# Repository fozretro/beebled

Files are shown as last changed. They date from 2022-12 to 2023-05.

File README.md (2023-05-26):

BeebLED
=======

So after nearly a year at this point (24th Nov 2022) of learning electronics, "re"collecting various retro computers, modifying and fixing them. I figured I would revist a childhood dream to have my own scrolling message board! Just like the ones down my local kebab shop! So lets build an LED matrix scroller for the Beeb! The proof of concept can be found [here](https://www.reddit.com/r/beneater/comments/xq2d4h/completed_6502_project_with_led_scroller/).

You can also see a demo video [here](https://drive.google.com/file/d/1L_YhwlXpUD0SaMJsGKrx3CFpbm8zI_nu/view).


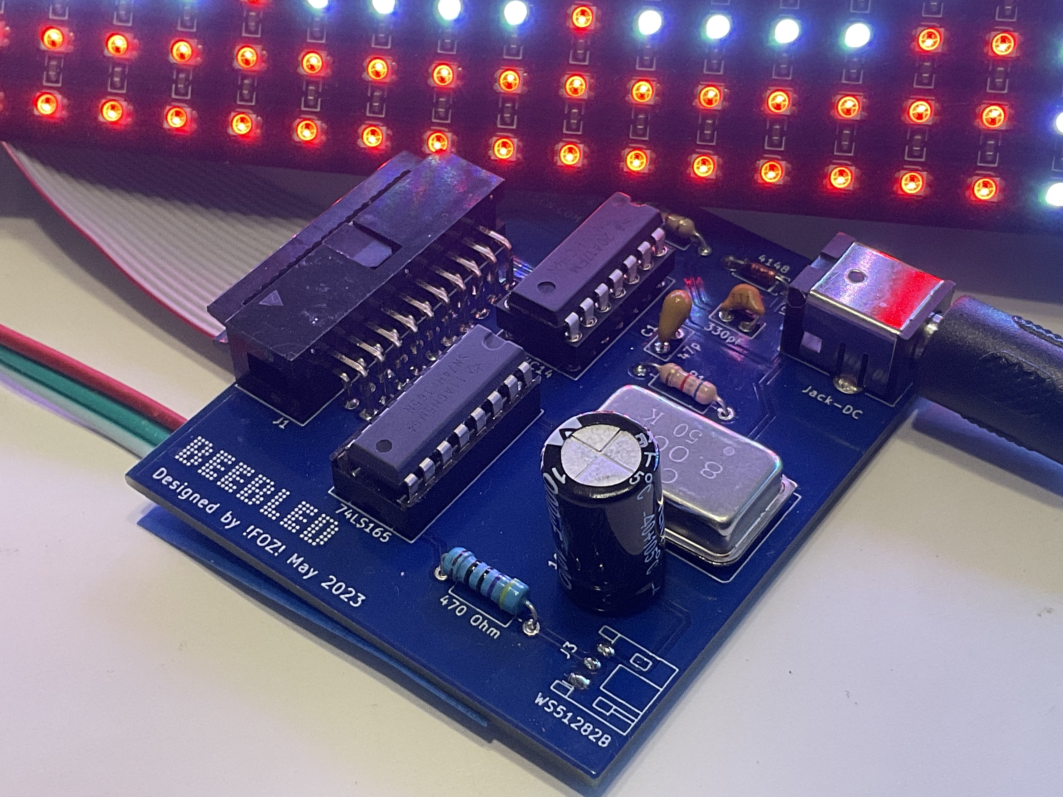
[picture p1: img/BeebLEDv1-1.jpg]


Credits
=======
- [Ben Eater](https://eater.net/6502), for opening my eyes to the joy of hardware and software building together!
- [Anders Brauner Nielsen](https://abnielsen.com), his well timed [blog](https://abnielsen.com/2021/12/23/ws2812b-rgb-lights-on-a-6502/) turned up (to my suprise) in my web searches for 6502 and LEDs! His ingenious circuit, with some additional components and modificaitons is at the core of this solution! Thank you Anders!
- [StarDot Forums](https://stardot.org.uk/forums/), the place for advice and encourgement for all your Acorn projects! This project uses [BeebASM](https://github.com/stardot/beebasm), [UPURSFS](https://www.retro-kit.co.uk/UPURS/) and [Visual Studio Code Extension for BeebASM](https://marketplace.visualstudio.com/items?itemName=simondotm.beeb-vsc). The authors of these amazing tools also hangout on stardot!

Usage
=====

It is a little early in development to complete this section, though my eventual goal is some kind of ROM, possibly using sideways RAM to avoid using the main RAM. Maybe even a VDU driver to plot stuff on the LED display? For now please see [this StarDot Forum thread](https://stardot.org.uk/forums/viewtopic.php?f=3&t=26047).

Developmet Tools
================

The ```/dist``` always contains the latest .ssd, but if you want to try to build it locally this section contains my notes on how I set things up with UPURSFS.

- Shift+Command+B bulds stuff and copies over to ```/dev/beebled``` and ```/dist```
- Shift+Ctrl+T launches the emulator (hard coded to where I have it)
- See below for connecting Beeb to the ```/dev/beebled``` folder to test hardware

Running UPURSFS and TubeHost
----------------------------

This enables the fastest possible inner loop for development, build on the Mac and instantly the compiled output is visble to the connected Beeb! This is especially useful since the only way (currently without mocking) is to see results is on real hardware.

**On the Beeb**, have UPURSFS ROM installed and pressing U+Break, U+Crl+Break or U+Shift+Break. If it says (No RTS) things are not connected - check the cable. See general instructions in the ```/bin/UPURSFS/Tubehost/README.txt```. ```*HSTATUS``` is a good test command. Press Ctrl+U+Break to boot the ```/dev/beebled``` disc on the Beeb. Note if you have ```Configure BOOT``` setup you have to use Ctrl+U+Break, if this gets frustrating just switch auto boot off.

**On the Mac**, you need to run ```/bin/UPURSFS/TubeHost/TubeHost.perl```. I had some issues running it and posted on StarDot forums what I found and my fix, see [here](https://stardot.org.uk/forums/viewtopic.php?f=3&t=24976) and also other tips.

```perl ./bin/UPURSFS/TubeHost/TubeHost.perl -U /dev/cu.usbserial-FTCL544Z```

By default the files it serves up to the BBC are in ```$HOME/Beeb_Disks```, however the above script has been modified to serve from ```/dev```. Note that when working on the files on the Beeb changes are also instantly reflected as well. For example when editing the sprites using the native Acorn GFX sprite editor and commands as described below.

Updating Sprites
----------------

Sprites can be used in the scroller and use the Acorn GFX sprite file format. You must then use the Acorn GFX Sprites ROM if on Master (as shown below), or one of the others if on other systems to edit. Note if you use a Master to edit the sprites and use the ROM in Sideways RAM the reminder of the ram bank is used for your sprites storage nice! Bellow is using indirect way of loading via memory as on UPURS ```SRLOAD``` command hangs.

```*LOAD R.SPRITES 3000```

```*SRWRITE 3000 6000 8000 4```

```*SLOAD Sprites```

Use commands like ...

```*SEDIT 1```

```*SDELETE 1```

```*SRENUMBER 4 1```

Then use to save ... (last two commands if on UPURS only)

```*SSAVE Sprites```

```*HTSTATUS```

```*CLOSE```

TODO's
======

Software
--------
- Add support #s command to support sprites of different heights (hard coded to 8)
- Build config. for the MODE2 emulation of LED output (consider using MODE 8)
- Remove hard coded mode2 calculated rows table and replace with asm macro script?
- Add config to support different size led panels, constants and logic behavior hard codedto 11x44
- It is not optimized other than having a secondary display buffer to ensure consistent timing output to the LED. Likely when I share this further, it can be optimized even further with feedback. 
- Implement 1 pixel scroll (currently 2 pixel)
- Eventually I would like to have the code in a ROM, e.g. *BEEBLED Hello World, or *BEEBLED #m3000 (displays whats on screen), and/or maybe a VDU driver? Not sure what to do about storage, use sideways ram if ROM loaded into sideways ram bank? Otherwise take PAGE?

Hardware
---------
- Experiment with adding additional 11x44 pixel matrix for longer and/or wider displays

Development Diary
=================

26th May 2023
-------------
- Made some fixes to the schematic and PCB design
- 1/ flipped diode around
- 2/ removed pcb JST connector (could not find one for JST SM based connectors) and replaced with pin headers and annotated 
- 3/ increased footprint size of 1000uF capacitor 
- 4/ added a little more labelling on the pcb
- 5/ updated to v1.2
- I kinda like it without a case and don't have the skills or hardware to design one (nor time, space, $ to invest at this point in that hobby)
- So I am thinking once the hardware design is stable I will turn full attention to the software TODO's above
- Next step is to double check above changes and send off for a new PCB, build it and test it

20th May 2023
-------------
- Week prior to today, the PCB arrived from PCBWay, along with various components
- Assemebling on and off during weekday evenings
- First test failed!
- Made a quick hack to the code to simply flip 1 LED off and on with a keypress, should add this in the future as a flag
- After compariing with the prototype and studying the PCB layout, realized i flipped the diode footprint on the PCB layout!
- Also found that the matrix JST connector I used is to small
- Have the breadboard prototype to compare signals really helped!
- After a soldering the matrix fly lead diretly to the PCB for now, and flipping the diode, success!
- Next job fix the PCB design, and source larger JST connector, also publish a BOM
- Then build the next version!

5th May 2023
------------
- Reproduce the circuit in Kicad
- Design the PCB in Kicad
- Build PCB via PCBWay
- Share the designs

Dec 25th
--------
- Removed hard coded font and used OS API to get character definitions

Dec 24th
--------
- Updated flash screen with new BeebLED logo
- Shorter default message with new holiday themed sprite!
- Published repo on fozretro GitHub
- Made a video shared on StarDot

Dec 21-23rd
-----------
- Implemented expressing sprite, text color changes and pause in message string

```#cX - Text color where x is 0-7```

```#pX - Pause for 0-9 seconds```

```#sX - Scroll on sprite 0-9 for now assumed 8 pixels with, but can be variable width```

```#dX - Display sprite 0-9 then scroll```

- Acorn GFX sprites are stored in logical top-down order for rows but right-left order horizontally, would love to know why?!?! Optimization in the sprite plotting code?

Dec 20th
--------
- Fixed the colors on the LED since moving to how true Mode 2 pixels are encoded
- Its not the most performant code right now - more tables or something needed in the future
- Refactored a little into two other .asm files
- Added some commands as follows

```#cX - Text color where x is 0 to 7```

```#sp - Pause for 0 to 9 seconds```

```#d - Display sprite 0```

Dec 19th
--------
- Broke the pixel coloring being output to the LED, since using true Mode 2 pixel encoding
- Removed hard coded scrolling message and splash screen
- Now loads from Acorn GFX sprite file and text file respectively
- Very strange format for sprites not sure how performant it will be to scroll in sprites
- Oh and implemented a debug feature to write to mode 2 screen as well as the LED
- Made sure all files under ```/dev/beebled``` are also copied to ```.ssd```

Dec 18th
--------
- In understanding the Acorn GFX sprite editor I mostly spent a few hours realizing my encoding for MODE 2 I had in mind was wrong and does not match the Beebs after all!
- So I wanted some way to easily add graphics into the scroller and decided to investigate the Acorn GFX sprite editor and its file format ... (later read same on StarDot doh)
    - File length - 2 bytes (including these two bytes)
    - Number of spirtes in file (not zero based) - 1 byte
    - Sprite
        - width (in bytes - base zero) - 1 byte
        - height (in bytes - base zero) - 1 byte
        - size (in bytes) - 2 byte
        - mode - 1 byte
        - id - 1 byte
        - data - bytes
- Ideas for message text format and making BeebLED configurable!
    - Scroll on a sprite, sprites smaller than 11 pixels in height get a border
    - Option to just display it a sprite on a clear screen then scroll
    - Scroll text uses built in font (for now!)
    - Pause the scrolling for x seconds
    - Change scroll direction 
    - Syntax ideas... ```#S1 #P5 This is the rest of the message... I #S2 my Beeb!```
    - Have sprites dynamically loaded, if ```Sprites``` file exists
    - Have message dynanically loaded, if ```Message``` file exists
- Added GFX ROMS and setup dummy config files Sprites and Message
- Drew the very early prototype splash screen from Sarah and stores in ```Sprites```

Dec 16th
--------
- Added basic argument reading to pass in different messages (really just to play with it for now - want to make a set of ROM commands for this). Now supports ```*BEEBLED My Message!```
- Exit the app on key press back to command line

Dec 12th
--------
- Fixed most of the gitter I  was seeing by remove fly leds, attach end of cable direct to breadboard - it still occurs now and again - but not enough to stop me progressing with some more of the software side of things

Dec 11th
--------
- Ported over code from my Ben Eater project which used a different compiler and memory addreses.
- Success! We have LED scroller powered by a BBC Micro!
- Well with the some glitching, which I think is due to fly leads etc. So I think I will atttempt to direct connect the User Port cable end more directly to the board with some pins.
- This is quite a milestone, so once I can fix the glitching I'll do a share on stardot
- Next up make the software a bit more accessible, to pass a message in from the command line
- After that likely I can split my time between software and progressing a schematic and pcb

Dec 10th
---------
- After much reading and re-learning I probed each of the steps in converting the Beebs clock pulse into a pulse to latch the data into the serial output IC. I noticed the inversion happening and decided to use an additional input/output on the 74HC14, 6A and 6Y, to have pulse generated on the actual Beebs pulse, not the inversion of it.
- I also found that if I have the LEDs to bright, the signal I think suffers and LEDs remain on or don't show the correct color. I probably need some more smoothing capactitors in some place?!?! Anyway the software fix was to low the brightness and hey presto it all stablized! I fill the 11x44 matrix with pixels and toggled them on and off with success. 
- Next up more fun with software for a bit! Scrolling message here we come!

Dec 4th
-------
- WIP > Coping over some code from my very first prototype [here](https://www.reddit.com/r/beneater/comments/wd6irw/ben_eater_6502_computer_driving_ws2812b_rgb_leds/) - trigger based on keypress as no timer code setup yet
- Partial success I can toggle an LED and show a strip of them..... but the signals are out
- However on closer inspection the data signal to LED matrix is missing the first bit of each byte sent via CB2, it sends a 0 and then only the first 7 bits from CB2 are being sent. Looking at it through my scope I can see that the small pulse sent to the PL pin is being sent to soon before data on CB2 starts to be sent. Afterwards due to timing the second pulse picks up the tail end of the first bit of data from CB2, but by this time the circuit has of course sent 1 of 8 bits.
-When I look at the data sheet for mode 110 it does show this as well. The odd thing is on the Ben Eater system above it worked fine (I plan to do more compares at the weekend with my scope).

Dec 2nd, 3rd
--------
- Built a new breadboard of the circuit to send to LED matrix I used for my Ben Eater computer [here](https://www.reddit.com/r/beneater/comments/wd6irw/ben_eater_6502_computer_driving_ws2812b_rgb_leds/)
- Tested on the above and works fine - yay!
- Will it work on the Beeb though? Is the data line to long? Had sights of clitchs on the original breadboard when this was the case?

27th Nov
--------
- Labelled up some GND, CB1 and CB2 fly leads from the cable socket ready to plug into breadboard
- Write some basic code that sets up the VIA and send bytes (keyboard input)so I could monitor with my scope to check the basic serial output is working from beeb user port. Monitoring CB1 and CB2 shows signals as expected. Nice!
- Also fixed !BOOT

26th Nov
--------
- Udpated the README with some info on the dev tools and captured pinout for user port
- Some good notes [here](https://stardot.org.uk/forums/viewtopic.php?t=11671) on testing user port
- I tested my cable pins do have 5v on them yay!

24th Nov
--------
- Built a BBC user port cable and tested continuity it with my meter
- Setup this project with various VSCode tasks and levergaging the UPURSFS file system to make stuff available instantly on the connected Beeb for testing.

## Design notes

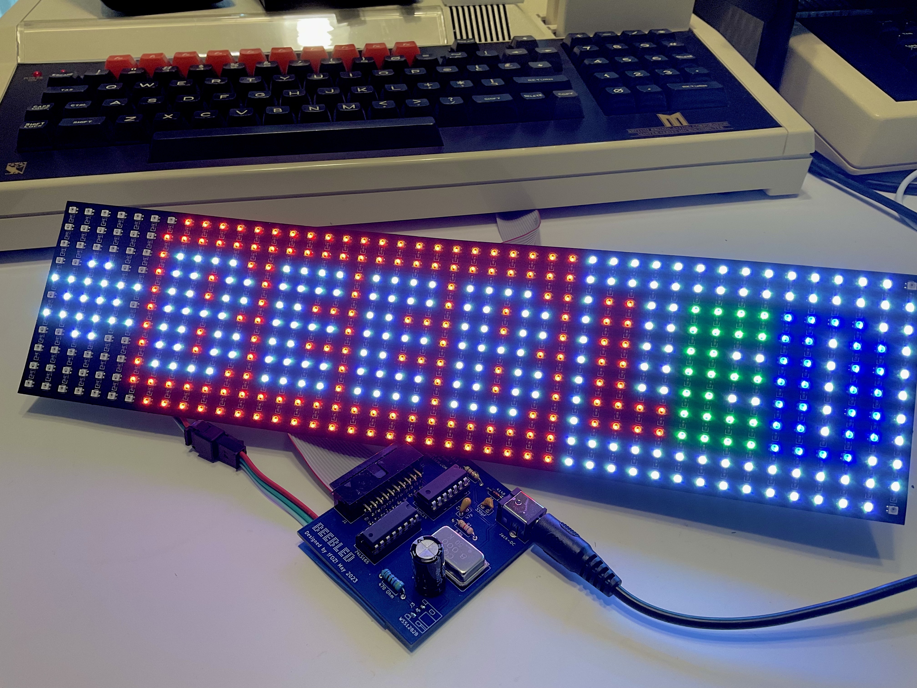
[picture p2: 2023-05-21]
img/BeebLEDv1-1Large.jpg

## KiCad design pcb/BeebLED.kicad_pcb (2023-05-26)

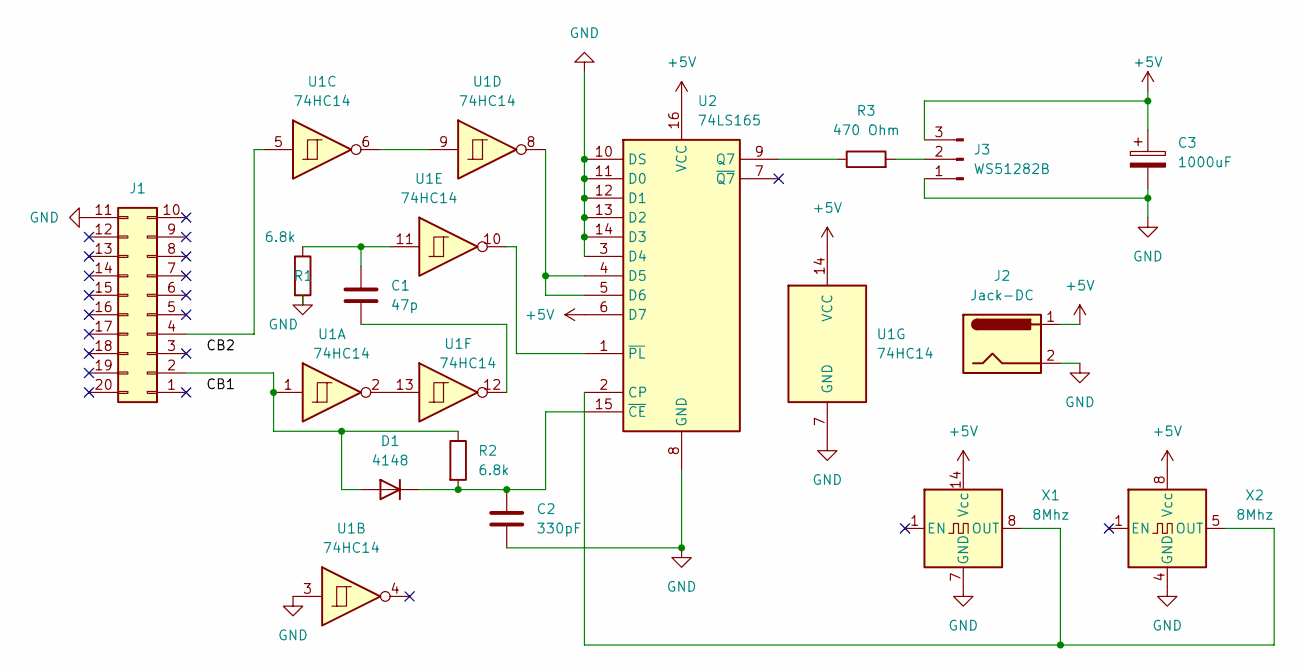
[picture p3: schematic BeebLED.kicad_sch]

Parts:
C1: 47p; C_Disc_D5.0mm_W2.5mm_P2.50mm
C2: 330pF; C_Disc_D5.0mm_W2.5mm_P2.50mm
C3: 1000uF; CP_Radial_D10.0mm_P5.00mm
D1: 4148; D_A-405_P7.62mm_Horizontal
J1: IDC-Header_2x10_P2.54mm_Horizontal
J2: Jack-DC; BarrelJack_CUI_PJ-063AH_Horizontal_CircularHoles
J3: WS51282B; PinHeader_1x03_P2.54mm_Vertical
R1, R2: 6.8k; R_Axial_DIN0207_L6.3mm_D2.5mm_P10.16mm_Horizontal
R3: 470 Ohm; R_Axial_DIN0207_L6.3mm_D2.5mm_P10.16mm_Horizontal
U1: 74HC14; DIP-14_W7.62mm_Socket
U2: 74LS165; DIP-16_W7.62mm_Socket
X1: 8Mhz; Oscillator_DIP-14
X2: 8Mhz; Oscillator_DIP-8

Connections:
+5V: C3.1, J2.1, J3.3, U1.14 (VCC), U2.6 (D7), U2.16 (VCC), X1.14 (Vcc), X2.8 (Vcc)
GND: C2.2, C3.2, J1.11, J2.2, J3.1, R1.2, U1.3, U1.7 (GND), U2.3 (D4), U2.8 (GND), U2.10 (DS), U2.11 (D0), U2.12 (D1), U2.13 (D2), U2.14 (D3), X1.7 (GND), X2.4 (GND)
unnamed: C1.1, R1.1, U1.11
unnamed: C1.2, U1.12
unnamed: C2.1, D1.2 (K), R2.2, U2.15 (~CE)
unnamed: D1.1 (A), J1.2, R2.1, U1.1
unnamed: J1.4, U1.5
unnamed: J3.2, R3.2
unnamed: R3.1, U2.9 (Q7)
unnamed: U1.6, U1.9
unnamed: U1.8, U2.4 (D5), U2.5 (D6)
unnamed: U1.10, U2.1 (~PL)
unnamed: U1.2, U1.13
unnamed: U2.2 (CP), X1.8 (OUT), X2.5 (OUT)

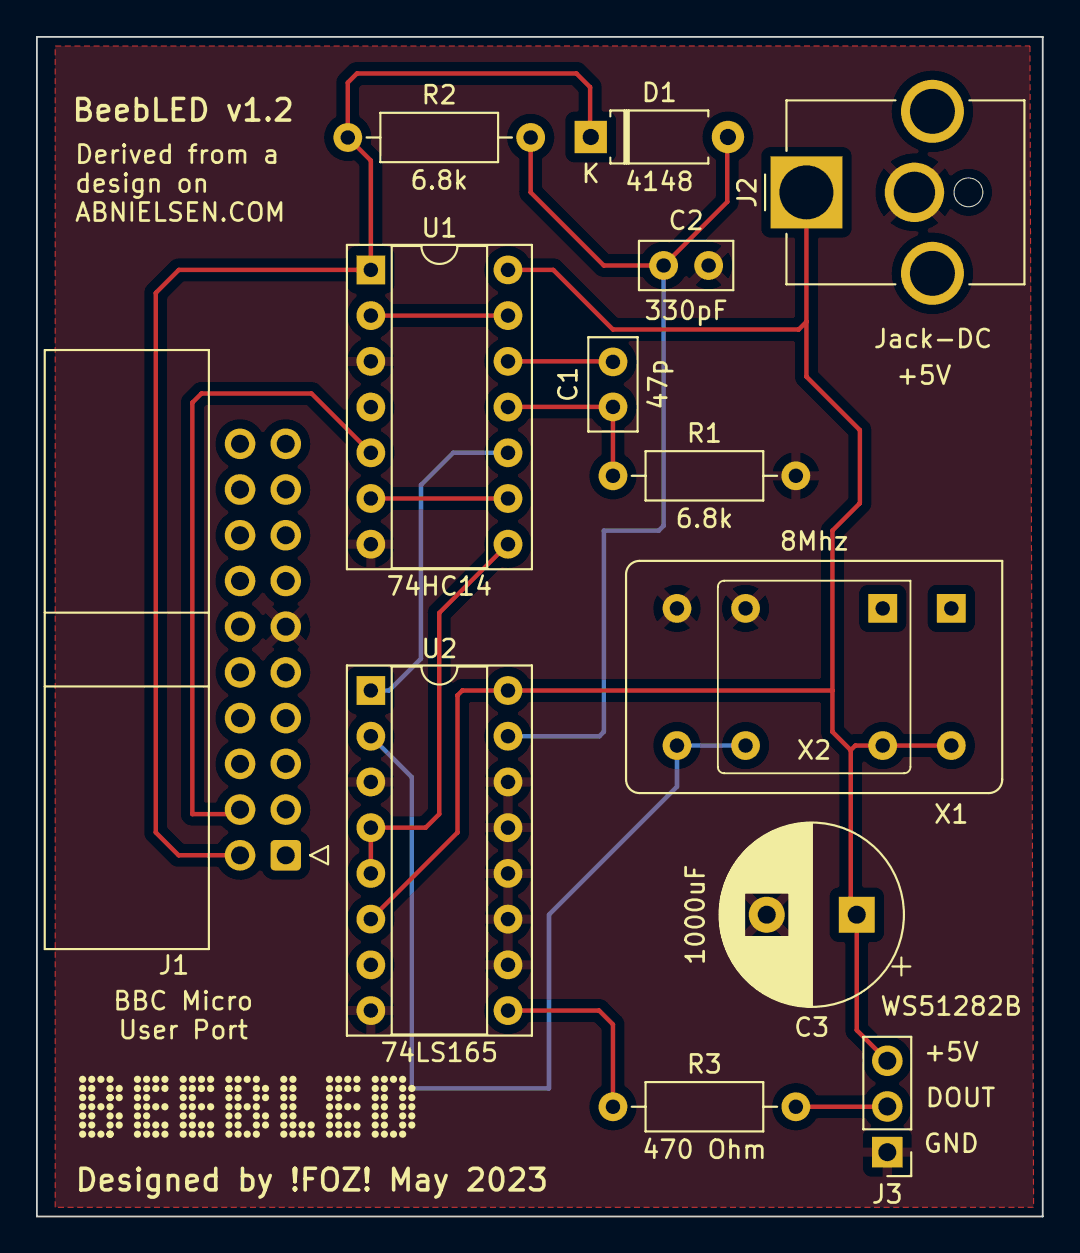
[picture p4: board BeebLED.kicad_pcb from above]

Board: 2 copper layers, 55.9 x 65.5 mm, 14 parts (0 on the bottom side), 14 nets.

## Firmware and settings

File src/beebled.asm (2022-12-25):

; OS Routines
OSWORD=&FFF1
OSWRCH=&FFEE
OSRDCH=&FFE0
OSBYTE=&FFF4
OSARGS=&FFDA
OSFILE=&FFDD
KEYCODE=&EC
; various constants
LED_WIDTH = 44
LED_HEIGHT = 11
LED_BUFFER_END_TOKEN = $FF
LED_BUFFER_PAGE_SIZE = 255 ; Page size enough for 85 pixels (4bpp)
LED_SIZE_BYTES = LED_WIDTH * LED_HEIGHT / 2; Number of bytes used to store display (4bpp)
COLOR_BLACK = 0
COLOR_RED = 1
COLOR_GREEN = 2
COLOR_YELLOW = 3
COLOR_BLUE = 4
COLOR_MEGENTA = 5
COLOR_CYAN =6
COLOR_WHITE = 7
; idx into sprite file header
SPRITE_FILE_HEADER_FILESIZE = 0 ; 2 bytes
SPRITE_FILE_HEADER_NUMBER_OF_SPRITES = 2 ; 1 byte
SPRITE_FILE_HEADER_SPRITES_DATA = 3 ; sprites data
SPRITE_FILE_HEADER_HEADER_SIZE = 3; Size in bytes (not zero basedO of above header)
; idx into sprite entry header
SPRITE_HEADER_WIDTH = 0 ; zero based - 1 byte
SPRITE_HEADER_HEIGHT =1 ; zero based - 1 byte
SPRITE_HEADER_SIZE = 2; 2 bytes
SPRITE_HEADER_MODE = 4; 1 byte
SPRITE_HEADER_ID = 5; 1 byte
SPRITE_HEADER_DATA = 6; Start of sprite data (length per above)
SPRITE_HEADER_HEADER_SIZE = 6; Size in bytes (not zero based) of above sprite header 
; zero page usage - during init
sprite_data_addr = $0070; 2 bytes
sprite_data_size = $0072; 2 bytes
; zero page usage - during main execution
pixel_bytes = $0070; represents the start of the following 3-bytes
red = $0070 ; used by sendPixel
green= $0071 ; used by sendPixel
blue = $0072 ; used by sendPixel
left_pixel_color = $0073 ; output of decodePixel
right_pixel_color = $0074 ; output of decodePixel
led_screen_offset = $0075 ; 1 byte
led_screen_row_number = $0076 ; 1 byte
led_screen_row_offset = $0077 ; 1 byte
led_screen_base = $0078; 2 bytes
led_output_buffer_addr = $007A ; 2 bytes
temp1 = $007C; 1 byte
display_address_map_addr = $007D ; 2 bytes
scroll_message_text_left_pixel = $007F ; 1 byte
scroll_message_idx = $0080 ; 1 byte
scroll_message_subidx = $0081 ; 1 byte - points to column from char def or sprite being scorlled
; unused = $0082  ; 2 bytes point to char def structure
scroll_sprite_addr= $0082 ; 2 bytes point to spride def structure, see SPRITE_HEADER_
; unused = $0084  ; 8 bytes
scroll_sprite_width = $0084 ; 1 byte
scroll_sprite_height = $0085 ; 1 byte
scroll_message_text_right_pixel = $008C; 1 byte
scroll_new_buffer = $008D; 11 bytes representing new pixels to scroll into view
temp2 = $0099 ; 1 byte

ORG &1900

.start
include "src/ledsend.asm"
include "src/leddisplay.asm"
include "src/beebledscroller.asm"

.messageFile
  EQUS "Message",&0D
.spritesFile
  EQUS "Sprites",&0D

.osfileBlk
  EQUW 0 ; Address of file
  EQUD 0 ; Load address of file	
  EQUD 0 ; Execution address of file.	
  EQUD 0 ; Start address of data for write operations, or length of file for read operations	
  EQUD 0 ; End address of data, that is byte after last byte to be written or file attributes.	

.exec
    jsr init

.mainloop
    LDA #2
    jsr ezwait
    jsr scroll_led
    lda KEYCODE 
    beq mainloop
    lda #&15 ; clear keyboard buffer
    ldx #0
    jsr OSBYTE
    rts

.scroll_led
    ; scroll message text
    jsr scroll_message
    ; take pixels from scroll_new_buffer and insert into right most pixel
    jsr update_led_rightmost_pixels;
    ; horizontal scroll 2 pixels (since we are 4bpp)
    inc led_screen_offset
    lda led_screen_offset
    ; have we overflowed screen memory?
    cmp #LED_SIZE_BYTES
    bcc scroll_led_no_screen_overflow 
    lda #0
    sta led_screen_offset
.scroll_led_no_screen_overflow
    ; update display based on current offset
    jsr update_led_display
    rts

.init
    ; init 6522
    ;     76543210              76             5      432               1      0
    LDA #%01011000 ; T1 control 01, T2 control 0, SRC 110 (Mode 6), PB1 0, PB2 0
    STA ACR ; 6522 ACR register, T1 continuous, PB7 disabled, Shift Out Ø2 (for the LED)
    ; look for "Sprites" file?
    lda #<spritesFile
    sta osfileBlk 
    lda #>spritesFile
    sta osfileBlk+1
    lda #5 ; just get file attrs, A=0 if not found
    ldx #<osfileBlk
    ldy #>osfileBlk
    jsr OSFILE
    cmp #0
    beq init_no_sprites_file
    lda #0
    sta osfileBlk+6 ; instruct OSFILE to load into a specific addr
    sta osfileBlk+7 ; instruct OSFILE to load into a specific addr
    lda #<sprite_data
    sta osfileBlk+2 
    lda #>sprite_data
    sta osfileBlk+3
    lda #&FF ; load "Sprites" file data (must be in Acorn GFX ROM format)
    ldx #<osfileBlk
    ldy #>osfileBlk
    jsr OSFILE
    jsr init_build_sprite_map
.init_no_sprites_file
    ; command line text to scroll message buffer?
    lda #1
    ldx #&70
    ldy #0
    jsr OSARGS
    ldy #0
.init_arg_loop
    lda (&70),Y
    sta scroll_message_buffer,y
    iny
    cmp #&0D 
    bne init_arg_loop
    ; look for "Message" file if no command line text given
    lda scroll_message_buffer
    cmp #&0D
    bne init_scroll_message_loaded
    ; look for "Message" file
    lda #<messageFile
    sta osfileBlk 
    lda #>messageFile
    sta osfileBlk+1
    lda #5 ; just get file attrs, A=0 if not found
    ldx #<osfileBlk
    ldy #>osfileBlk
    jsr OSFILE
    cmp #0
    beq init_scroll_message_loaded 
    lda #0
    sta osfileBlk+6 ; instruct OSFILE to load into a specific addr
    sta osfileBlk+7 ; instruct OSFILE to load into a specific addr
    lda #<scroll_message_buffer
    sta osfileBlk+2 
    lda #>scroll_message_buffer
    sta osfileBlk+3
    lda #&FF ; load the Message file data
    ldx #<osfileBlk
    ldy #>osfileBlk
    jsr OSFILE
.init_scroll_message_loaded
    ; initilize start of the display data and output to led matrix
    lda #0
    sta led_screen_offset;
    lda #<led_display ; low byte of led display memory
    sta led_screen_base;
    lda #>led_display ; high byte of led display memory
    sta led_screen_base+1;
    lda #<display_address_map; 
    sta display_address_map_addr ; low byte of display address map
    lda #>display_address_map; 
    sta display_address_map_addr+1 ; high byte of display address map
    jsr update_led_display
    ; init scroller routines
    lda #0
    sta scroll_message_idx
    sta scroll_message_subidx
    lda left_pixel_color_value+COLOR_MEGENTA
    sta scroll_message_text_left_pixel
    lda right_pixel_color_value+COLOR_MEGENTA
    sta scroll_message_text_right_pixel
    rts
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

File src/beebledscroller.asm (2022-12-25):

; code for the main scroll routine and command parsing

.scroll_message_buffer;
  SKIP 256; 256-byte -  max 255 chars

.scroll_message_pixels_handler_addr
  EQUD $0000

.left_pixel_color_value
       ;--4-2-1-
  EQUB %00000000 ; black   0
  EQUB %00000010 ; red     1
  EQUB %00001000 ; green   2
  EQUB %00001010 ; yellow  3
  EQUB %00100000 ; blue    4
  EQUB %00100010 ; magenta 5
  EQUB %00101000 ; cyan    6
  EQUB %00101010 ; white   7

.right_pixel_color_value
       ;---4-2-1
  EQUB %00000000 ; black   0
  EQUB %00000001 ; red     1
  EQUB %00000100 ; green   2
  EQUB %00000101 ; yellow  3
  EQUB %00010000 ; blue    4
  EQUB %00010001 ; magenta 5
  EQUB %00010100 ; cyan    6
  EQUB %00010101 ; white   7

.scroll_char_def_block
.scroll_char_value
    EQUB 0
.scroll_char_def 
    EQUD &00000000
    EQUD &00000000

.scroll_message
    lda scroll_message_subidx
    cmp #0 ; still scrolling current char pixels?
    beq scroll_message_process_next_char
.scroll_message_scroll_handler
    jmp (scroll_message_pixels_handler_addr) ; scroll_message_scroll_char_pixels or scroll_message_scroll_sprite_pixels
.scroll_message_process_next_char
    ldx scroll_message_idx  
    lda scroll_message_buffer,x ; get the char ASCII value
    cmp #&0D
    bne scroll_message_process_char ; end of string?
    ldx #0 ; reset back to start of mesage
    lda scroll_message_buffer,x ; get the char ASCII value of the first character
.scroll_message_process_char
    inx ; increment for next character
    stx scroll_message_idx ; and store
    cmp #'#' ; special command?
    beq scroll_message_command
    sta scroll_char_value ; input into following OSWORD call to read char def
    lda #&A ; OSWORD Read character definition
    ldx #<scroll_char_def_block
    ldy #>scroll_char_def_block
    jsr OSWORD
    lda #<scroll_message_scroll_char_pixels ; set pixel scroller callback handler to scroll the character pixels
    sta scroll_message_pixels_handler_addr
    lda #>scroll_message_scroll_char_pixels
    sta scroll_message_pixels_handler_addr+1

.scroll_message_scroll_char_pixels
    ldx #0
    ldy #0
    lda #3 ; red line at the top
    sta scroll_new_buffer,y ; store it
    iny 
    lda #0 ; blank line
    sta scroll_new_buffer,y ; store it
    iny 
.scroll_message_scroll_char_rows ; process each charater row
    lda scroll_char_def,x
    clc
    rol a ; roate bits left
    sta scroll_char_def,x
    lda #0
    adc #0 ; includes carry flag
    beq scroll_message_scroll_char_no_pixel1 ; pixel?
    lda scroll_message_text_left_pixel ; set pixel on left
.scroll_message_scroll_char_no_pixel1
    sta scroll_new_buffer,y ; store it
    lda scroll_char_def,x 
    clc
    rol a ; rotate bits left (again, since we are 4bpp)
    sta scroll_char_def,x 
    lda #0
    adc #0 ; includes carry flag
    beq scroll_message_scroll_char_no_pixel2 ; pixel?
    clc
    lda scroll_new_buffer,y
    ora scroll_message_text_right_pixel; set pixel on right
    sta scroll_new_buffer,y ; store it
.scroll_message_scroll_char_no_pixel2
    inx
    iny
    cpx #8
    bne scroll_message_scroll_char_rows ; processed all 8 chardef rows?
    lda #3 ; red line at the bottom
    sta scroll_new_buffer,y ; store it
    inc scroll_message_subidx ; increment for next 2 bits
    lda scroll_message_subidx
    cmp #4 ; all 8 bits proessed? 
    bne scroll_message_scroll_end
    lda #0
    sta scroll_message_subidx ; reset to grab next character
.scroll_message_scroll_end
    lda #0
    rts

.scroll_message_command
    lda scroll_message_buffer,x ; character following the # that has already been parsed
    inx 
    stx scroll_message_idx ; ready for next char
    cmp #'c' ; change text color
    beq scroll_message_command_color
    cmp #'p' ; pause for x seconds
    beq scroll_message_command_pause
    cmp #'s' ; scroll on sprite
    beq scroll_message_command_scroll_sprite
    cmp #'d' ; display a sprite
    beq scroll_message_command_display_sprite
    ; not a command...
    dec scroll_message_idx ; rollback one char - this is not command/droid we where looking for
    jmp scroll_message ; resume reading from message

.scroll_message_command_color ; e.g. #c
    jsr scroll_command_read_value ; returns in X
    lda left_pixel_color_value,x
    sta scroll_message_text_left_pixel
    lda right_pixel_color_value,x
    sta scroll_message_text_right_pixel
    jmp scroll_message ; resume reading from message

.scroll_message_command_pause ; e.g. #p
    jsr scroll_command_read_value ; returns in X
.scroll_message_command_pause_wait
    lda #50 ; wait for 50 vsync
    jsr ezwait
    dex
    cpx #0
    bne scroll_message_command_pause_wait
    jmp scroll_message ; resume reading from message

.scroll_message_command_scroll_sprite ; e.g. #s
    jsr scroll_command_read_value ; returns in X
    jsr scroll_command_sprite_def
    ldy scroll_sprite_width 
    sty scroll_message_subidx ; counts down as we scroll the sprite    
    lda #<scroll_message_scroll_sprite_pixels ; set pixel scroller callback handler to scroll the sprite pixels
    sta scroll_message_pixels_handler_addr
    lda #>scroll_message_scroll_sprite_pixels
    sta scroll_message_pixels_handler_addr+1

.scroll_message_scroll_sprite_pixels
    ldx #0
    lda #SPRITE_HEADER_HEADER_SIZE-1
    clc
    adc scroll_message_subidx
    tay
.scroll_message_scroll_sprite_pixels_loop
    lda (scroll_sprite_addr),y
    sta scroll_new_buffer+2,x ; assuming 8 pixel height 
    tya
    clc
    adc scroll_sprite_width
    tay
    inx
    cpx scroll_sprite_height
    bne scroll_message_scroll_sprite_pixels_loop
    ; red top and bottom border
    lda #3
    sta scroll_new_buffer
    sta scroll_new_buffer+10
    lda #0
    sta scroll_new_buffer+1
    ; process next pixels in sprite next time round
    dec scroll_message_subidx
    rts

.scroll_message_command_display_sprite ; e.g. #d
    jsr scroll_command_read_value ; returns in X
    jsr scroll_command_sprite_def
    ldy #SPRITE_HEADER_DATA ; y is the index into sprite data (limits sprite size to <256)
    lda scroll_sprite_width
    sta scroll_message_subidx
    tax
.scroll_message_command_display_sprite_copy
    lda (scroll_sprite_addr),y ; currently hard coded to sprite 0 11x44 pixels (242 bytes)
    iny ; move forward ready for next sprite byte
    dex ; work backwards storing in the led display memory (Acorn GFX sprites are stored horizontally mirrored)
    sta led_display,x
    dec scroll_message_subidx ; all row pixels processed?
    bne scroll_message_command_display_sprite_copy
    txa
    clc
    adc #(LED_WIDTH/2)
    adc scroll_sprite_width
    tax
    lda scroll_sprite_width
    sta scroll_message_subidx
    dec scroll_sprite_height
    bne scroll_message_command_display_sprite_copy
    lda #0 ; above code assumes screen is at scroll offset 0 
    sta led_screen_offset;
    sta scroll_message_subidx
    jsr update_led_display
    jmp scroll_message ; resume reading from message
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

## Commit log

2022-12-25 Replaced hard coded font with calls to OS to get chardef
    Users can also now customize the font and add special characters via traditional means prior to calling BeebLED
    [beebled.asm, beebledscroller.asm]
2023-05-05 Added schematic and pcb
    [BeebLED.kicad_pcb, BeebLED.kicad_sch]
2023-05-05 Fixed 8 Mhz not connected
    [BeebLED.kicad_pcb, BeebLED.kicad_sch]
2023-05-06 Changed J3 connector type and tied U1 Pin 3 to GND
    Thanks to the advice from stardot! :-)
    [BeebLED.kicad_pcb, BeebLED.kicad_sch]
2023-05-06 Added support for DIP8 crystal
    [BeebLED.kicad_pcb, BeebLED.kicad_sch]
2023-05-07 Added alternative X2 component to schema and updated PCB
    [BeebLED.kicad_pcb, BeebLED.kicad_sch]
2023-05-07 Added a logo
    [BeebLED.kicad_pcb]
2023-05-07 Generated gerber files
    [BeebLED-B_Cu.gbr, BeebLED-B_Mask.gbr, BeebLED-B_Paste.gbr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]
2023-05-26 Updated to v1.2 schematic and pcb design
    Requires further testing
    [BeebLED.kicad_pcb, BeebLED.kicad_sch]
2023-05-27 Updated fabrication files
    [BeebLED-B_Cu.gbr, BeebLED-B_Mask.gbr, BeebLED-B_Paste.gbr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]
